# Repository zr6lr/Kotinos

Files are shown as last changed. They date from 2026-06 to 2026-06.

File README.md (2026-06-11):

# Kotinos: Finger tip shell mod for HSK Pro
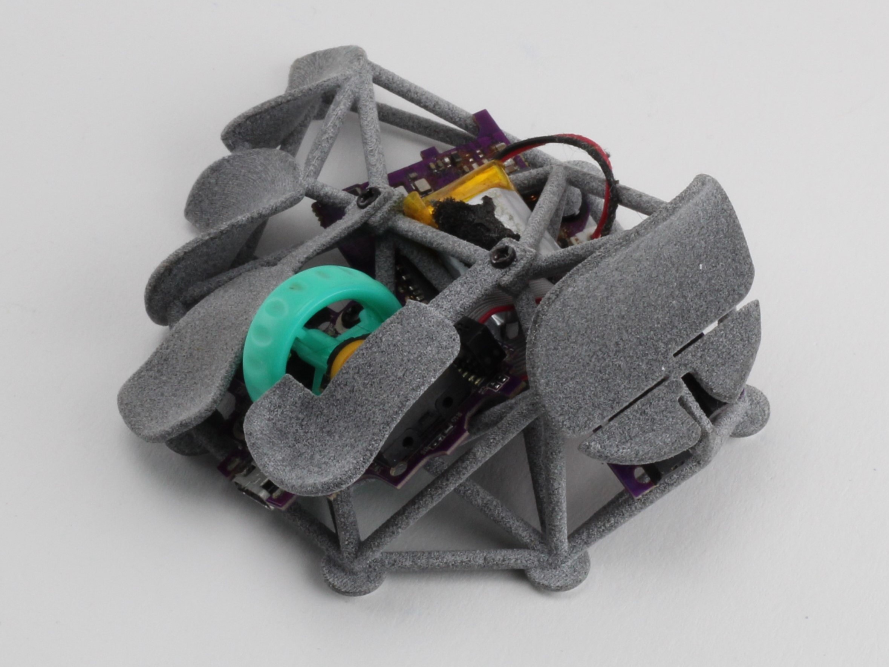
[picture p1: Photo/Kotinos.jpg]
Main


STLs are provided, but if you wish to modify them you can edit the SCAD files. Additional [BOSL2](https://github.com/BelfrySCAD/BOSL2) library is required.

This project is open sourced with the GPL-3.0 license. The license conditionally allows for commercial use, modification, distribution, patent, and private use. Please take note of the license conditions before utilizing this project.

## BOMs
|  | Part Name | Part Description | Quantity | Source |
| :---: | ----- | ----- | :-----: | ---- |
| 1 | Husk Pro | Mouse | 1 | [G-Wolves](https://shop.g-wolves.com/products/g-wolves-hsk-pro-4k) |  
| 2 | Kotinos | Main Shell | 1 | 3D Print Kotinos.stl |
| 3 |Index Paddle | Paddle for Right Mouse Button | 1 | 3D Print IndexPaddle.stl |
| 4 |Middle Paddle | Paddle for Left Mouse Button | 1 | 3D Print MiddlePaddle.stl |
| 5 | IDC Female Connector | 1.27mm pitch Mini dual rows IDC FC 10 pins Female | 1 | [amazon](https://www.amazon.com/Accessories-Connectors-Transition-Terminates-FC-10P-10PK/dp/B014BFVAUS?th=1)| 
| 6 | IDC Male Connector |1.27mm pitch Mini dual rows IDC FC 10 pins Male | 1 | [amazon](https://www.amazon.com/Accessories-Connectors-Transition-Terminates-FD-10P-20PK/dp/B07FD47BQD?th=1) |
| 7 | Ribbon Cable | 3cm length of 0.635mm pitch flat ribbon cable | 1 |  |
| 8 | M1.4 3mm | Thumb PCB Mount | 3 | |
| 9 | M1.4 3mm wide head |  Mounting Sensor PCB, Index PCB, and Paddles | 8 | HSK Pro |
| 10 | 6~7mm Skates | circular mouse skates | 7 | |

## Assembly Instruction

- Disassemble HSK Pro: Battery, side button PCB, encoder + buttons PCB, Sensor PCB and harvest ~8 screws
- Encoder wheel tends to slide off due to the tent angle; apply a dab of superglue on the wheel axis to fix it in place.
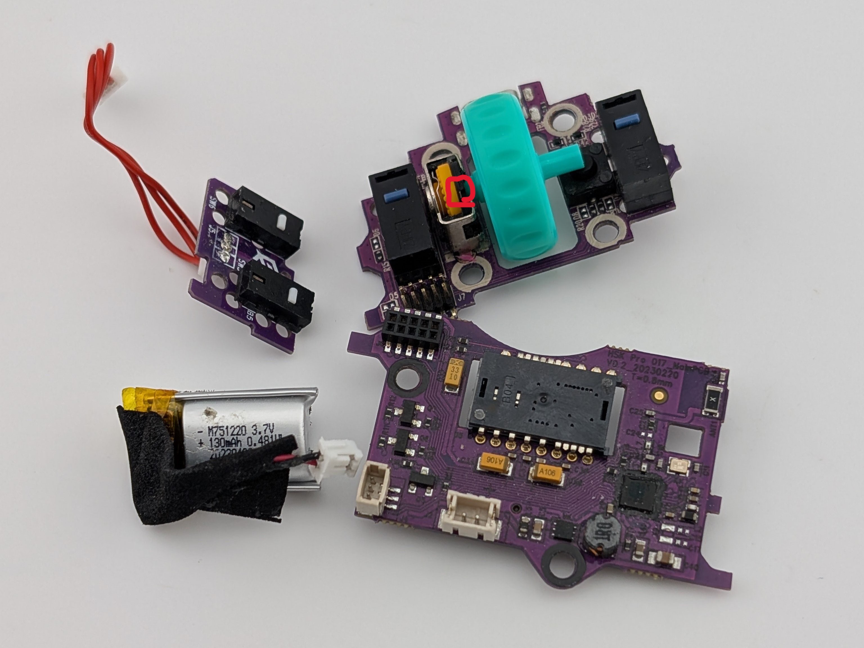
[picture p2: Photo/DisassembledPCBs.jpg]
PCBs
	
- Attach the side PCB to the shell first: use M1.4 3mm narrow head on the center post, M1.4 3mm narrow head near the notch and on the far corners
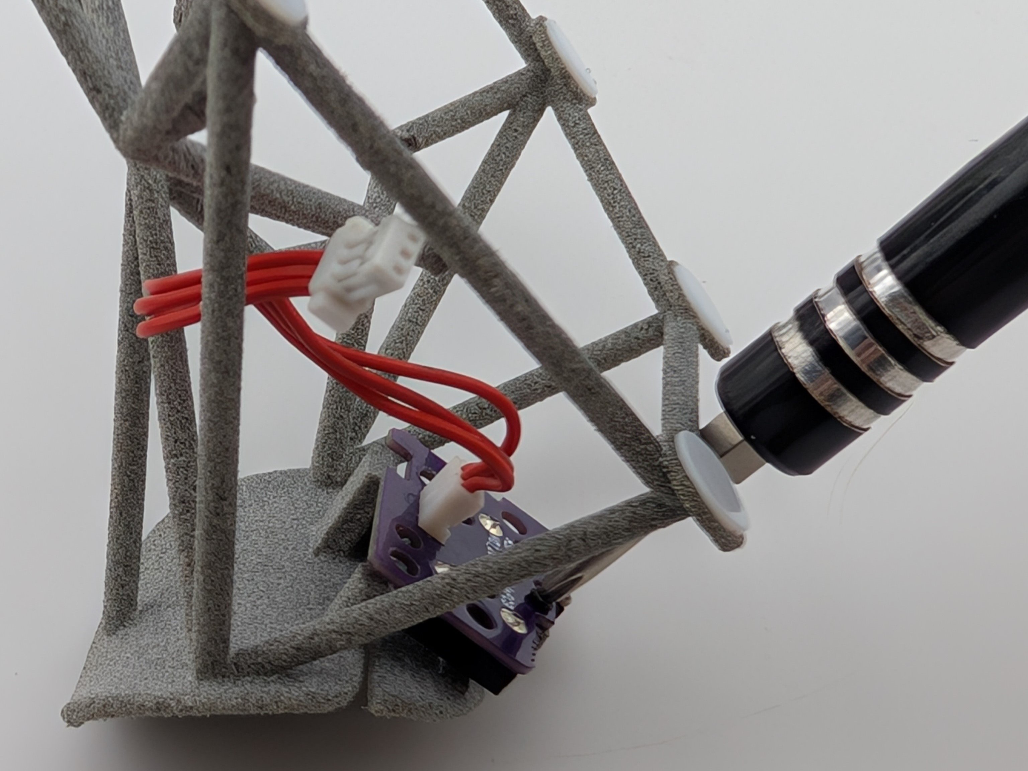
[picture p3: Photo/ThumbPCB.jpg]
Thumb PCB
  
- Next is the sensor PCB: attach the jumper first, then slide it on to the shell and secure it with 2 M1.4 wide heads
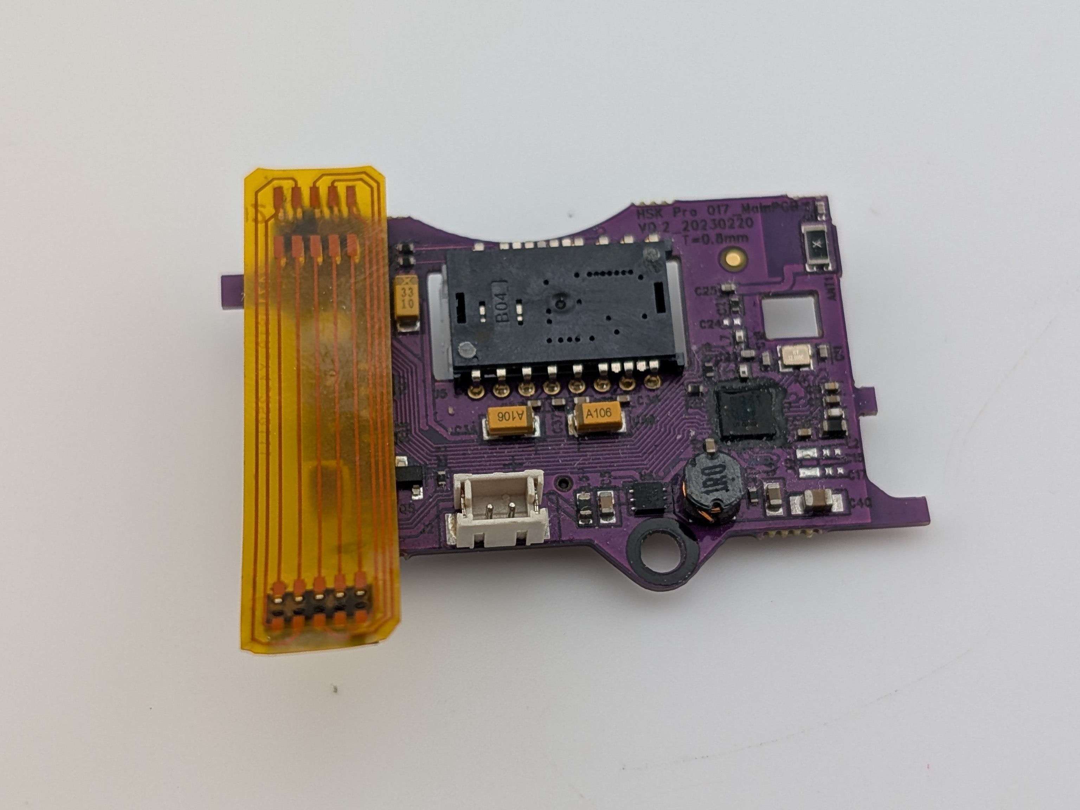
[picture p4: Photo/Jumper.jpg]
Jumper old
  
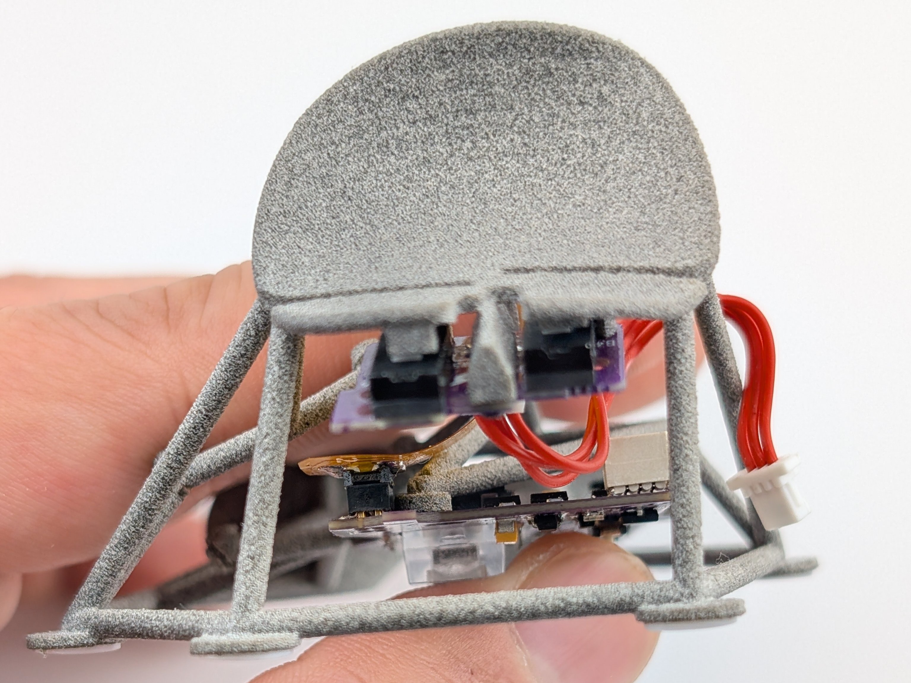
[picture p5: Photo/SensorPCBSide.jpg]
Side
  
- Attach the index PCB: first, secure the top 4 mount points with M1.4 wide heads. Attach the jumper then secure the paddles.
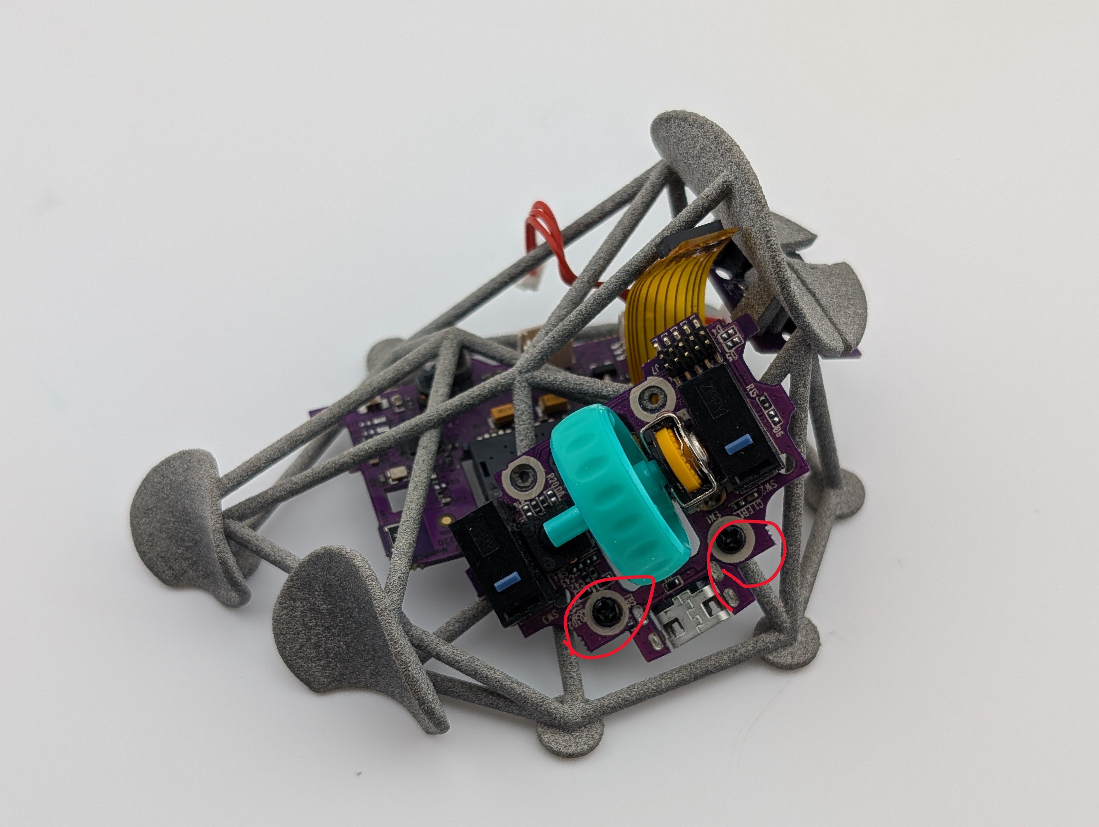
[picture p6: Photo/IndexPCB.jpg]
Index Mound
  
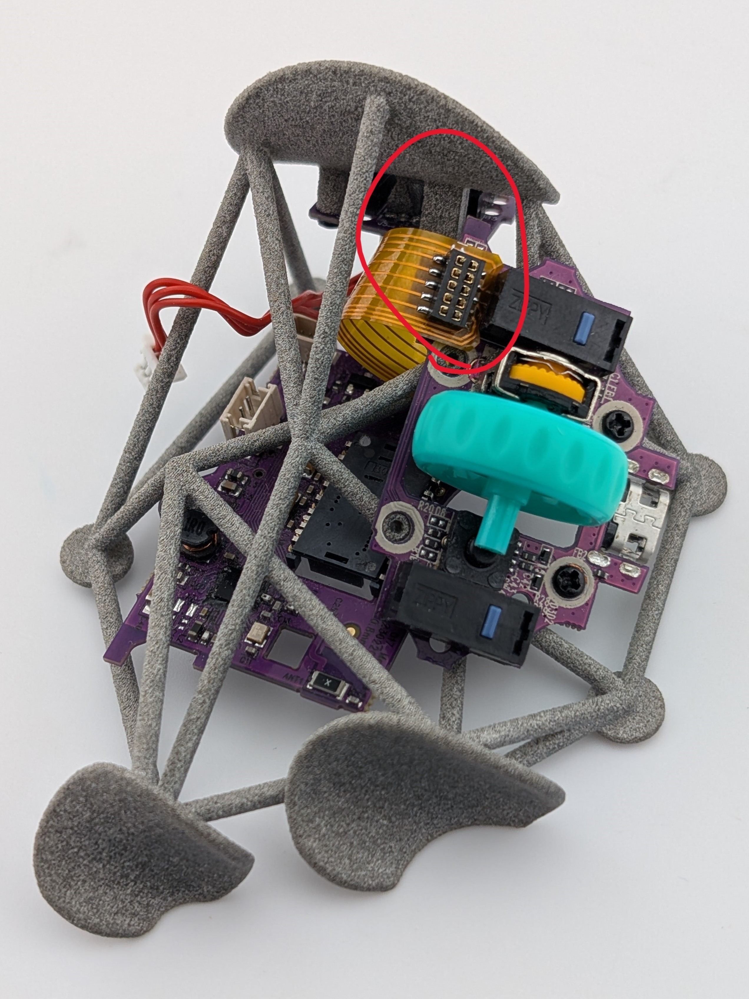
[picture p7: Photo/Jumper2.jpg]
Jumper2
	
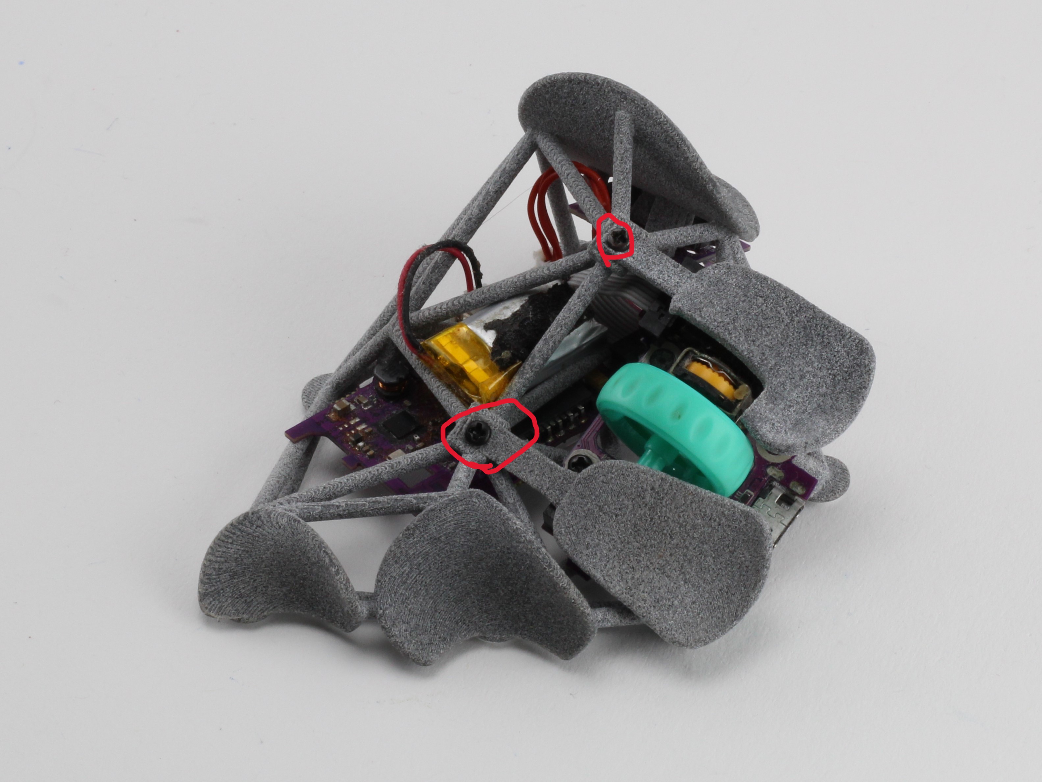
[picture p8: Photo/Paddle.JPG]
Paddles
	
- Finally, plug in the side PCB jumper and the battery. You can slide in battery between the shell to secure it.
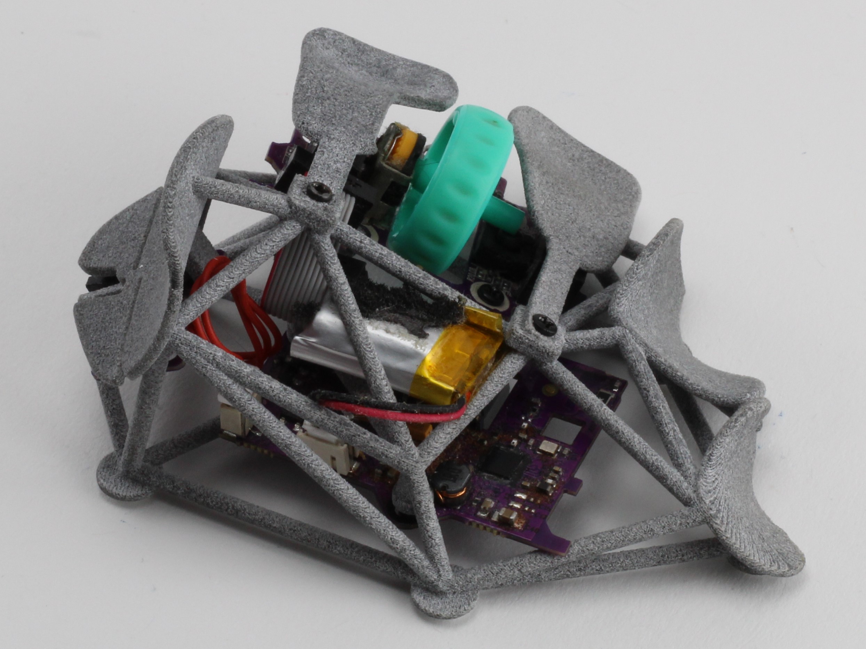
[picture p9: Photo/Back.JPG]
Back Shot
 

## Customization
Edit the following files to suit your need
- DataHand.scad stores the hand measurement that dictates the paddle placement
- Data*Finger*Paddle.scad for paddle surface modification
- MainBuild.scad to render modules and edit module placements
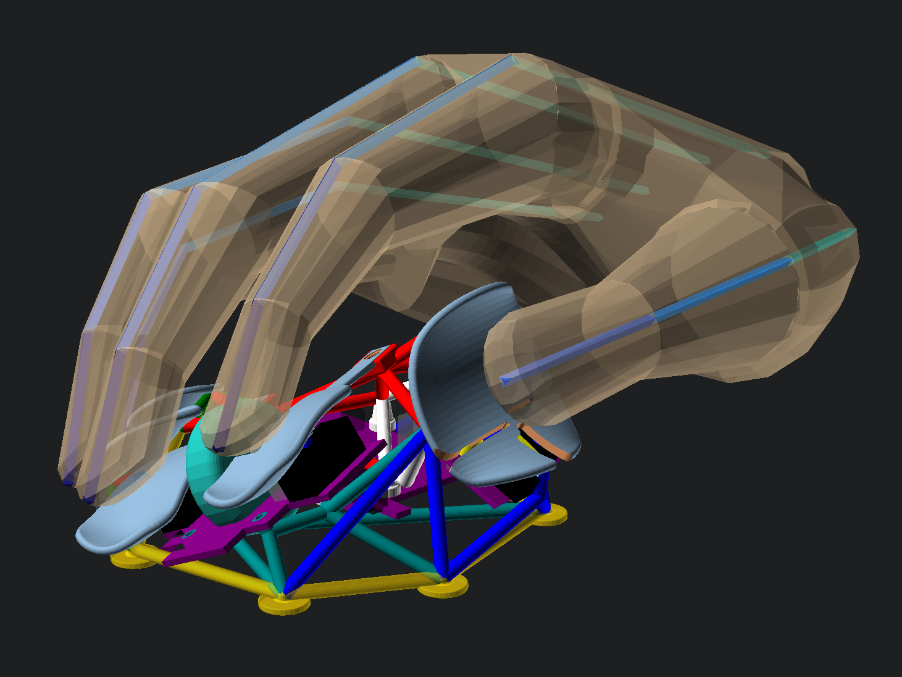
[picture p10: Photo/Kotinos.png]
Preview


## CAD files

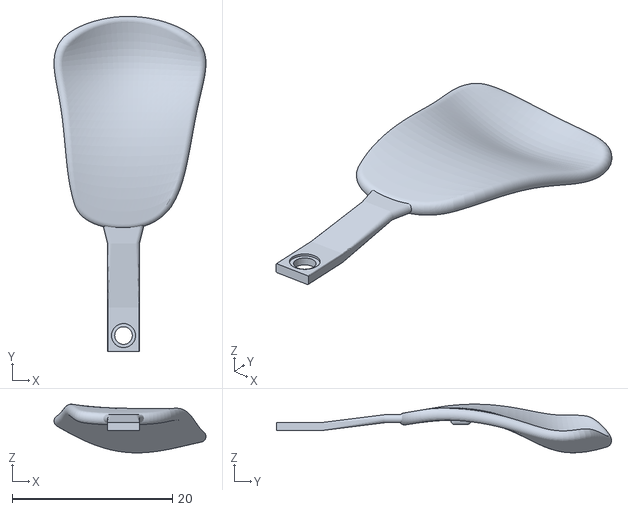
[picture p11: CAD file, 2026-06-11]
STL/MiddlePaddle.stl
19.0 x 41.8 x 6.08

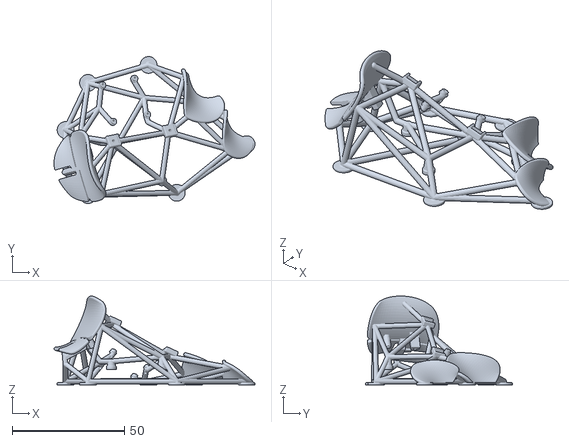
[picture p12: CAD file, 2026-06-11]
STL/Kotinos.stl
89.6 x 65.5 x 39.6

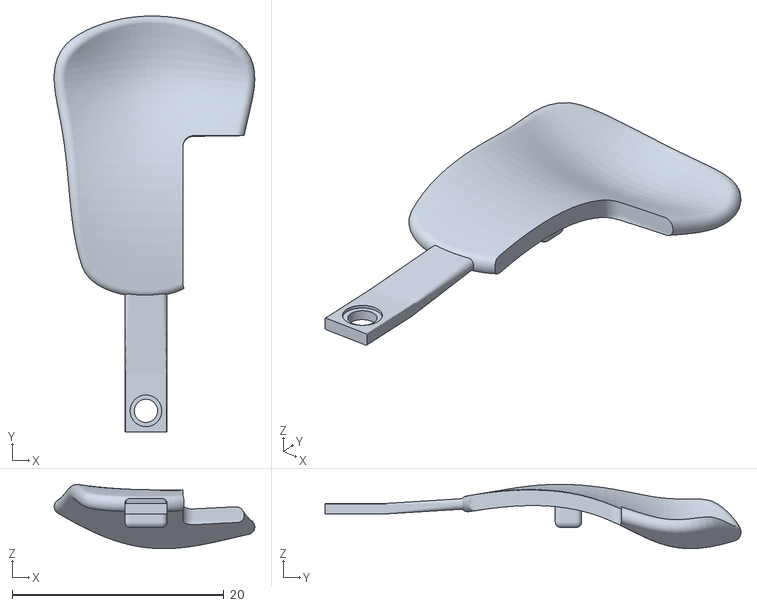
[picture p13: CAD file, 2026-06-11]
STL/IndexPaddle.stl
19.0 x 39.3 x 6.08

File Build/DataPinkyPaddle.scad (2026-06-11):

/*  
Bug Note: issue with flipped face orientation vectors. Use another software to realign (i.e. Blender)
 */ 
//include <PaddleSurfaceGenerator.scad>

// 
PinkyPatch = [
               [[        ], [  5, 4, 4], [  7, 0,  5], [ 9, -4,  3], [           ]],
               [[ 3, 7, 3], [  2, 4, 1], [  2, 0,  0], [ 3, -4,  -1], [  4,-8, -5]],
               [[ 0, 9, 4], [  0, 5, 1], [  0, 0,  0], [ 0, -4, -2], [  0,-8, -5]],
               [[-5, 9, 6], [ -4, 5, 0], [-6, 1, 1], [-4., -4,  -1], [ -4,-7, -6]],
               [[        ], [ -7, 5, 11], [-11, -1,  4], [-8, -3, -3], [           ]]
              ];  


//%PatchPaddle(PinkyPatch, debug=true); //comment out when redner
//color("gold", alpha=.5)PatchPaddle(PinkyPatch, debug=false);

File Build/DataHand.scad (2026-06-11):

/*USER INPUT*/
//input is in mm and degree 

/*Critical Parameters*/
  //pseudo metacarpal origin [x,y,z] translation in mm, extrapolate metacarpal to carpal wrist joint (set global origin as middle carpal base) 
  origin_thumb_carpal_base  =  [-25,-15,-15]; 
  origin_index_carpal_base  =  [-16,0,-2]; 
  origin_middle_carpal_base =  [0,0,0]; 
  origin_ring_carpal_base   =  [17,0,-3]; 
  origin_pinky_carpal_base  =  [31,0,-6];

  //Digit Lengths
  //Pseudo Metacarpal Length: Dorsal side base of wrist to knuckle, ignore carpals 
  length_thumb_metacarpal  = 53; //mm
  length_index_metacarpal  = 65; //mm
  length_middle_metacarpal = 70; //mm
  length_ring_metacarpal   = 68; //mm
  length_pinky_metacarpal  = 59; //mm

  //Proximal Phalanges Length: Dorsal side knuckle to proximal-middle interphalangeal joint  
  length_thumb_proximal  = 35; //mm
  length_index_proximal  = 47; //mm
  length_middle_proximal = 52; //mm
  length_ring_proximal   = 45; //mm
  length_pinky_proximal  = 36; //mm

  //Middle Phalanges Length: Dorsal side proximal to distal interphalangeal joint
  length_thumb_distal  = 29; //mm
  length_index_middle  = 28; //mm
  length_middle_middle = 31; //mm
  length_ring_middle   = 28; //mm
  length_pinky_middle  = 21; //mm

  //Proximal Phalanges Length: Dorsal side distal joint to the tip of finger 
  length_index_distal  = 23; //mm
  length_middle_distal = 24; //mm
  length_ring_distal   = 26; //mm
  length_pinky_distal  = 20; //mm

//Flexion Angles [pitch, roll, yaw] in degrees 
  //Thumb 
  thumb_metacarpal = [-14, -80, 42.75]; 
  thumb_proximal   = [-25, 0, 0];
  thumb_distal     = [-10, 0, 0];
  thumb_adduction  = [0,0,-22]; 

  //Index 
//  index_metacarpal = [ -1, 0, 3]; 
//  index_proximal   = [-24, 0, 6];
//  index_middle     = [-42, 0, 0];
//  index_distal     = [-25, 0, 0];
  index_metacarpal = [ -1, 0, 4]; 
  index_proximal   = [-37, 0, 6];
  index_middle     = [-25, 0, 0];
  index_distal     = [-16, 0, 0];
  //Middle 
  middle_metacarpal = [  0, 0, 0];
  middle_proximal   = [-40, 0, 0];
  middle_middle     = [-30, 5, 0];
  middle_distal     = [-13, 0, 0];
  //Ring
  ring_metacarpal = [ -2,  2,-5]; 
  ring_proximal   = [-30,  0, 1];
  ring_middle     = [-40,  5, 0];
  ring_distal     = [-15, 10, 0];
  //Pinky
  pinky_metacarpal = [ -6, 10,-10]; 
  pinky_proximal   = [-27,  0, -1];
  pinky_middle     = [-36,  5,  3];
  pinky_distal     = [-14, 10,  0];
  
/*END of Critical Parameters*/
         
// Cosmetic Params 
Finger_diam =  [ 
//meta, meta-prx joing, prx-mid, mid-dis //Finger thickness NOT WIDTH
    [39, 27, 16, 15, 0],//thumb
    [35, 25, 16, 11, 11],//ind
    [39, 26, 17, 12, 12],//mid
    [38, 25, 16, 12, 12],//ring
    [37, 21, 12, 9.5, 9.5],//pinkie
  ]/2;

Finger_width =  [ 
//meta, meta-prx joing, prx-mid, mid-dis tip //Finger thickness
    [27, 27, 16, 15, 0],//thumb
    [25, 25, 16, 11, 11],//ind
    [36, 20, 17, 12, 12],//mid
    [34, 21, 16, 12, 12],//ring
    [36, 17, 14, 12, 9.5],//pinkie
  ]/2;


Tip_thickness = [5,4,4,4,3]; //finger Tip thickness 
Tip_angle     = [60,60,55,50,60]; //finger tip face angle 
WebRatio=[.75, 0.6, 0.6, 0.5, 0.5];  //amount forward from meta prox joint used on finger webbing
fingerScale = 1.2; //Account for thickness to witch ratio, more for aethetics 


// Palmer blob  width  in mm
  pinkiePalmWid =32/2; 
  pinkiePalmHgt =28/2; 
  ringPalmWid = 10;
  ringPalmLen = 25; 
  midPalmWid = 10;
  midPalmLen = 17;

//Matrix struct for loopign  
Len_hand   =   [ // joint to joint lenght in mm  (NOTE: Dorsal side measurment)
                [length_thumb_metacarpal, length_thumb_proximal, length_thumb_distal,  0],//thumb
                [length_index_metacarpal, length_index_proximal, length_index_middle, length_index_distal],//ind
                [length_middle_metacarpal,length_middle_proximal,length_middle_middle,length_middle_distal],//mid
                [length_ring_metacarpal,  length_ring_proximal,  length_ring_middle,  length_ring_distal],//ring
                [length_pinky_metacarpal, length_pinky_proximal, length_pinky_middle, length_pinky_distal],//pinkie
               ];

NeutralHandFlexion = [
                      [ thumb_metacarpal,  thumb_proximal,  thumb_distal, thumb_adduction],  //last slot used as Thumb radial adduction data
                      [ index_metacarpal,  index_proximal,  index_middle,    index_distal], 
                      [middle_metacarpal, middle_proximal, middle_middle,   middle_distal], 
                      [  ring_metacarpal,   ring_proximal,   ring_middle,     ring_distal], 
                      [ pinky_metacarpal,  pinky_proximal,  pinky_middle,    pinky_distal]
                     ];

GripHandFlexion = [
                      [ thumb_metacarpal+[18,-3,0],  thumb_proximal-[22,0,0],  thumb_distal-[33,0,0], thumb_adduction+[0,0,-3]],  //last slot used as Thumb radial adduction data
                      [ index_metacarpal+[3,0,0],  index_proximal+[0,0,7],  index_middle-[25,0,0],    index_distal-[25/2,0,0]], 
                      [middle_metacarpal+[2,0,0], middle_proximal+[0,0,-2], middle_middle-[25,0,0],   middle_distal-[25/2,0,0]], 
                      [  ring_metacarpal+[2,0,0],   ring_proximal+[3,0, 1],   ring_middle-[29,0,0],     ring_distal-[29/2,0,0]], 
                      [ pinky_metacarpal+[3,0,0],  pinky_proximal-[1,0, 2],  pinky_middle-[30,0,0],    pinky_distal-[30/2,0,0]]
                     ];
                     
W_hand = [origin_thumb_carpal_base, 
          origin_index_carpal_base, 
          origin_middle_carpal_base, 
          origin_ring_carpal_base,
          origin_pinky_carpal_base
         ];  

/*---------------------------------- Builds check--------------------------*/
//include <BOSL2/std.scad>
//include <HandGenerator.scad>
//color("gold", alpha=.5)HandsOn(meat= false, GripHandFlexion);
//HandsOn(meat= false, NeutralHandFlexion);

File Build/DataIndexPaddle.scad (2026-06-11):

//include <PaddleSurfaceGenerator.scad>

DeepPaddlePatch=[
               [[        ], [ 9,15, -3], [ 8, 13,  -4], [ 7, 11,  -3], [ 7,9, -1], [ 6, 4,-.5], [  6, 0, -0], [          ]],
               [[ 4,19,-3], [ 3,15, -5], [ 2, 13,  -5], [ 2, 11,  -4], [ 2,9,-0.], [ 2, 4,  0], [  2, 0, -0], [  2,-6, -1]],
               [[-1,21,-6], [-1,15,-6.5], [-1, 13,-5.5], [-1, 11,-4.5], [-1,9,-0.5], [-1, 4,  0], [ -1, 0, -0], [ -1,-6, -1]],
               [[-6,19,-2], [-4,15, -5], [-4, 13,  -5], [-4, 11,  -4], [-4,9,-0.], [-4, 4,  0], [ -4, 0, -0], [ -6,-6, -1]],
               [[        ], [-10,15,-1], [-9, 13,  -2], [-8.5, 11,  -1], [-8,9,  0], [-8, 4,  1], [ -8, 0, -0], [          ]]
              ]; 

 ShallowPaddlePatch=[
               [[        ], [ 9,17,-1.5], [ 8, 13, -2], [ 7, 10, -0.5], [ 6, 5, .5], [  6, 0, -0], [          ]],
               [[ 4,21, 0], [ 3,17, -2], [ 2, 13, -3], [ 2, 10,   -1.0], [ 2, 5,  0], [  2, 0, -0], [  2,-6, -1]],
               [[-1,22,-2], [-1,17, -2.5], [-1, 13, -3.5], [-1, 10, -1.5], [-1, 5,  0], [ -1, 0, -0], [ -1,-6, -1]],
               [[-6,21, 0], [-4,17, -2], [-4, 13, -3], [-4, 10,   -1], [-4, 5,  0], [ -4, 0, -0], [ -6,-6, -1]],
               [[        ], [-8,17, -1], [-9, 13, -2], [-8, 10,   -0], [-8, 5,  1], [ -8, 0, -0], [          ]]
              ]; 
                   

//%PatchPaddle(ThumbPatch, debug=true); //comment out when redner
//color("gold", alpha=.5)
//PatchPaddle(ShallowPaddlePatch, debug=false);
//$fn=32;
//IndexDeepPaddle();



module PaddleMount () {
  difference(){
    fwd(10)xrot(90)prismoid(size1 =[4,1], size2= [4,1],shift=[0,0], h=5.5, rounding1=.1, rounding2= .1);
    fwd(13.5)cyl(d=2.2, 1);
    fwd(13.5)up(.4)cyl(d=3, .25);
  }      
}

module IndexShallowPaddle (shift =[0,0.0,-2]) {
  left(14)up(13.25)fwd(3)move(shift)scale([1,1.0,1])PatchPaddle(ShallowPaddlePatch, debug=false); //mid 
  move([-15.5,1,10.35+shift[2]/2-1.25])cuboid([4,2.5,4.+shift[2]+2.5],rounding=.5); 
  move([-15.5,-6.5,11.6]){
      up(+shift[2]){
        xrot(90)prismoid(size1 =[5,1], size2= [4,1], h=2, rounding=.5);
        zrot(180)xrot(90)prismoid(size1 =[5,1], size2= [6,.25],shift=[0,.75], h=2, rounding1=.5);      
        fwd(2)xrot(90)prismoid(size1 =[4,1], size2= [4,1],shift=[0,-2], h=8, rounding1=.5, rounding2= .1);
      }
      up(shift[2]-2)PaddleMount();
   }
}

module IndexDeepPaddle (shift =[0,-0.0,-1.5], scaling = [1,1,1]) {
  difference(){
    left(14)up(13.25)fwd(3)move(shift)scale(scaling)PatchPaddle(DeepPaddlePatch, debug=false); //mid 
    move([-8.5,-1.5,10])cuboid([7,15,5],rounding=1); 
  }
  move([-15.5,1,10.35+shift[2]/2-.4])cuboid([4,2.5,4.+shift[2]+.2],rounding=.5); //switch nib
  
  move([-15.5,-6.5,11.6]){
      up(+shift[2]){
        fwd(2)xrot(90)prismoid(size1 =[4,1], size2= [4,1],shift=[0,-.5], h=8, rounding1=.5, rounding2= .1);
      }
      up(shift[2])down(.5)PaddleMount();
   }
}

module MidPaddle (rend=false, scaling = [1,1.0,1],shift =[0,-0.5,-2.5]) {
  
  if(rend==true)left(14)up(13.25)move(shift)scale(scaling)import("\\husk\\mid_paddle2.stl"); //mid 
  else left(14)up(13.25)move(shift)scale(scaling)PatchPaddle(DeepPaddlePatch, debug=false); //mid 
//  left(14)up(13.25)move(shift)scale(scaling)PatchPaddle(DeepPaddlePatch, debug=true); //mid 
//  #xflip()import("\\husk\\husk_mid.stl"); //mid 
  
//  move([-15.5,1,10.6+shift[2]/2])cuboid([4,2.5,4.5+shift[2]],rounding=.5); //switch nib
  move([-15.5,1,10.6+shift[2]/2-.25])cuboid([4,2.5,4.+shift[2]],rounding=.5); //switch nib
  
  move([-15.5,-6.5,11.6]){
      up(shift[2]){
        xrot(90)prismoid(size1 =[5,1], size2= [4,1], h=2, rounding=.5);
        zrot(180)xrot(90)prismoid(size1 =[5,1], size2= [6,.25],shift=[0,.75], h=2, rounding1=.5);      
        fwd(2)xrot(90)prismoid(size1 =[4,1], size2= [4,1],shift=[0,-1.0], h=8, rounding1=.5, rounding2= .1);
      }
      up(shift[2]-1)PaddleMount();    
   }

}

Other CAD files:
Build/DataRingPaddle.scad
Build/DataThumbPaddle.scad
Build/HSK_PCB.scad
Build/HandGenerator.scad
Build/MainBuild.scad
Build/PaddleSurfaceGenerator.scad
